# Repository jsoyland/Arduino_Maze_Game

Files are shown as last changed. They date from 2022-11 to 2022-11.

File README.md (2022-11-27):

# Arduino Maze Game

We thought that it might be fun to make a "video game console" out of an Arduino and decided on a maze game.  

### Console
The design for the console was hand-drawn and then reproduced in OpenSCAD.

### Wiring 

We used a ILI9341 320x240 screen and an Arudino Nano.  Initially it only showed a white screen, but it tuns out that all its inputs require to be 3.3V, which meant we needed a 3.3V-5V logic level converter in between the Arduino and the screen.  With that in place, the wiring looks like:
|Display | Arduino |
| ----- | ----- |
| VCC | 3v3 |
| GND | GND | 
| CS | 10 | 
| RESET | 3v3 | 
| DC | 9 | 
| SDI(MOSI) | 11 | 
| SCK | 13|  
| LED | 3v3 | 
| SDO(MISO) | 12 | 
| T_CLK | 13 |
| T_CS | 8 |
| T_DIN | 11 |
| T_DO | 12 |
| T_IRQ | not connected |

We aren't using any of the touch capabilities here, though I went ahead and wired it up.  I don't totally understand it but Arduno has an ["SPI" interface](https://www.arduino.cc/reference/en/language/functions/communication/spi/) that the touchscreen and display devices both use.  The Output/Input/Clock pins are shared between the two peripherals, which the Chip Select is different (here it's pins 10 and 8).

Also wired up a joystick to control the maze:
| Thumbstick | Arduino |
| SW | 2 |
| VRY | A0 |
| VRX | A1 |
| +5V | 5V |
| GND | GND |

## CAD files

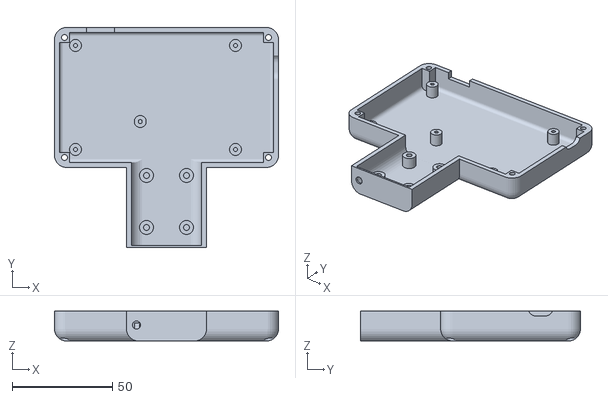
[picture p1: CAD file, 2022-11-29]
console.stl
112.0 x 110.0 x 15.0

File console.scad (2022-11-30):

// Higher definition curves
$fs = 0.01;


difference(){//temporary - cut off back half

union(){
    difference(){ 
        // Body
        union(){
            // Screen Box
            roundedcube([112, 70, 30], true, 6);
            // Handle
            translate([0, -70, 0]) roundedcube([40, 130, 30], true, 6);
        }

        //Screen Hole (67mm x 50 mm)
        translate([0, 0, 10]) cube([67.01, 50.01, 30], true);
        
        // Thumbstick hole
        translate([0, -52, 10]) cylinder(30, 11, 11, true);
        
        union(){ // Interior
            //screen
            //translate([0, 0, 0]) roundedcube([105, 65, 25], true, 6);
            translate([0, 0, 0]) roundedcube([107, 65, 25], true, 2);
            //handle
            translate([0, -70, 0]) roundedcube([35,125,25], true, 6);
        }
            
        // subtract rounded corners on display hole
        translate([0 , 0, .01]) 
            difference(){
                difference(){
                    translate([0, 0, 14.5]) cube([69, 52, 1], true);
                    translate([0, 0, 14.5]) cube([67, 50, 1.1], true);
                }
                
                union(){
                    translate([0, 26, 14]) rotate([90, 0, 90]) cylinder(70, 1, 1, true);
                    translate([0, -26, 14]) rotate([90, 0, 90]) cylinder(70, 1, 1, true);
                    translate([34.5, 0, 14]) rotate([90, 0, 0]) cylinder(52, 1, 1, true);
                    translate([-34.5, 0, 14]) rotate([90, 0, 0]) cylinder(52, 1, 1, true);
                }
        }

        // screw holes for screen
        translate([(110/2)-15, 0, 12.5-(3.43/2)]) {
                translate([0, 49/2, 0]) cylinder(7, 1.5, 1.5, true);
                translate([0, -49/2, 0]) cylinder(7, 1.5, 1.5, true);
        }

        translate([-((110/2)-10), 0, 12.5-(3.43/2)]) {
                translate([0, 49/2, 0]) cylinder(7, 1.5, 1.5, true);
                translate([0, -49/2, 0]) cylinder(7, 1.5, 1.5, true);
        }
        
       
        // screw holes for body
        
        translate([-30/2, -130, 0]) {
            cylinder(27.01, 1.5, 1.5, true);
            translate([0, 0, -14.5]) cylinder(2, 2.75, 2.75, true);
        }
        translate([30/2, -130, 0]) {
            cylinder(27.01, 1.5, 1.5, true);
            translate([0, 0, -14.5]) cylinder(2, 2.75, 2.75, true);
        }
        translate([102/2, 60/2, 0]) {
            cylinder(27.01, 1.5, 1.5, true);
            translate([0, 0, -14.5]) cylinder(2, 2.75, 2.75, true);
        }
        
        translate([102/2, -60/2, 0]) {
            cylinder(27.01, 1.5, 1.5, true);
            translate([0, 0, -14.5]) cylinder(2, 2.75, 2.75, true);
        }
        
        translate([-102/2, 60/2, 0]) {
            cylinder(27.01, 1.5, 1.5, true);
            translate([0, 0, -14.5]) cylinder(2, 2.75, 2.75, true);
        }
        
        translate([-102/2, -60/2, 0]) {
            cylinder(27.01, 1.5, 1.5, true);
            translate([0, 0, -14.5]) cylinder(2, 2.75, 2.75, true);
        }
        
        // Hole for switch
        translate([-33, 35, 1]){
            cube([14, 10, 9.5], true);
        }
        
        // Hole for USB-C port
        translate([55, 13, 1.5]){ 
            union(){
               //#translate([0, 2.25, 0]) rotate([0, 90, 0]) cylinder(10, 3.5, 3.5, true);  
               //#translate([0, -2.25, 0]) rotate([0, 90, 0]) cylinder(10, 3.5, 3.5, true);  
               translate([0, 2.25, 0]) rotate([0, 90, 0]) cylinder(10, 4, 4, true);  
               translate([0, -2.25, 0]) rotate([0, 90, 0]) cylinder(10, 4, 4, true);               
               cube([10, 4.5, 8], true );           
            }
        }
        
    }
    
    // close off battery compartment, but leave a 2x3mm hole for connector
     translate([0, -75, 0]) difference(){
       cube([35, 2, 25], true);
       translate([15, 0, -7]) rotate([90, 0, 0]) cylinder(4, 2, 2, true);
     }
            
    // Mounting blocks for screen.  
    // Height above base: 3.43 mm
    // Screw hole 3mm  
    translate([(110/2)-15, 0, 12.5-(4.44/2)]) 
        difference(){
            cube([5.00, 55, 4.43], true);
            translate([0, 50/2, 0]) cylinder(6, 1.5, 1.5, true);
            translate([0, -50/2, 0]) cylinder(6, 1.5, 1.5, true);
            cube([5.01, 44, 4.44], true);
        }
        
    translate([-((110/2)-10.01), 0, 12.5-(4.44/2)]) 
        // Bizzarely adding .01mm to x here addresses an 
        // "Object may not be a valid 2-manifold and may need repair!" error
        difference(){
            cube([5.00, 55, 4.43], true);
            translate([0, 50/2, 0]) cylinder(6, 1.5, 1.5, true);
            translate([0, -50/2, 0]) cylinder(6, 1.5, 1.5, true);
            cube([5.01, 44, 4.44], true);
        }
        
      // Standoffs for circuit board.  Trying cylinders
      circuit_board_standoff_height=6.5;
      translate([-(17/2)+4, 0, (-(25/2)+(circuit_board_standoff_height/2))]) 
        difference(){
            union(){
                translate([-82/2, 53/2, 0]) cylinder(circuit_board_standoff_height, 3, 3, true);
                translate([-82/2, -53/2, 0]) cylinder(circuit_board_standoff_height, 3, 3, true);
                translate([-82/2 + 33.38, -52/2 + 13.97, 0]) cylinder(circuit_board_standoff_height, 3, 3, true);
                translate([82/2, 53/2, 0]) cylinder(circuit_board_standoff_height, 3, 3, true);
                translate([82/2, -53/2, 0]) cylinder(circuit_board_standoff_height, 3, 3, true);
            }
            translate([-82/2, 53/2, 0]) cylinder(circuit_board_standoff_height+0.1, 1, 1, true);
            translate([-82/2, -53/2, 0]) cylinder(circuit_board_standoff_height+0.1, 1, 1, true);
            translate([-82/2 + 33.38, -52/2 + 13.97, 0]) cylinder(circuit_board_standoff_height+.1, 1, 1, true);
            translate([82/2, 53/2, 0]) cylinder(circuit_board_standoff_height+0.1, 1, 1, true);
            translate([82/2, -53/2, 0]) cylinder(circuit_board_standoff_height+0.1, 1, 1, true);
        }        

/*
    translate([-((110/2)-10), 0, 12.5-(4.94/2)]) 
        difference(){
            cube([5.00, 54, 4.93], true);
            translate([0, 49/2, 0]) cylinder(6, 1.5, 1.5, true);
            translate([0, -49/2, 0]) cylinder(6, 1.5, 1.5, true);
            cube([5.01, 43, 4.94], true);
        }
*/            
            
    // Mounting block for thumbstick
    thumbstick_standoff_height=6;
    translate([0, -50, -(25-thumbstick_standoff_height)/2]) {
        difference(){
            union(){
                translate([20/2, (26/2)-2, 0]) cylinder(thumbstick_standoff_height, 3.5, 3.5, true);
                translate([-20/2, (26/2)-2, 0]) cylinder(thumbstick_standoff_height, 3.5, 3.5, true);
                translate([-20/2, -(26/2)-2, 0]) cylinder(thumbstick_standoff_height, 3.5, 3.5, true);
                translate([20/2, -(26/2)-2, 0]) cylinder(thumbstick_standoff_height, 3.5, 3.5, true);
            }
            //cube([27, 36, 7], true);    
            translate([20/2, (26/2)-2, 0]) cylinder(thumbstick_standoff_height+.1, 1.5, 1.5, true);
            translate([-20/2, (26/2)-2, 0]) cylinder(thumbstick_standoff_height+.1, 1.5, 1.5, true);
            translate([-20/2, -(26/2)-2, 0]) cylinder(thumbstick_standoff_height+.1, 1.5, 1.5, true);
            translate([20/2, -(26/2)-2, 0]) cylinder(thumbstick_standoff_height+.1, 1.5, 1.5, true);
            //translate([0, -2, 0]) cube([27.01, 18.01, 7.01], true);
            //translate([0, 0, 0]) cube([12.01, 36.01, 7.01], true);
        }
    }
    
    // Body Screws - Whatever it's called, the bits that hold the halves together.
    
    //lower-left handle
    translate([-30/2, -130, 0]) difference(){
        cube([5, 5, 24.5], true);
        cylinder(26.1, 1.5, 1.5, true);
    }
    
    //lower-right handle
    translate([30/2, -130, 0]) difference(){
        cube([5, 5, 25], true);
        cylinder(26.1, 1.5, 1.5, true);
    }
  
    //upper-right display
    translate([102/2, 60/2, 0]) difference(){
        cube([5, 5, 24.5], true);
        cylinder(26.1, 1.5, 1.5, true);
    }
    
    //lower-right display
    translate([102/2, -60/2, 0]) difference(){
        cube([5, 5, 25], true);
        cylinder(26.1, 1.5, 1.5, true);
    }
    
    //upper-left display
    translate([-102/2, 60/2, 0]) difference(){
        //cube([5, 5, 25], true);
        cylinder(25, 2.5, 2.5, true);
        cylinder(26.1, 1.5, 1.5, true);
    }
    
    //lower-left display
    translate([-102/2, -60/2, 0]) difference(){
        //cube([5, 5, 25], true);
        cylinder(25, 2.5, 2.5, true);
        cylinder(26.1, 1.5, 1.5, true);
    }
    
}
    
    
// temporary - cut off back half
//translate([0, 0, -15]) cube([400, 400, 30], true);
// temporary - cut off front half
 translate([0, 0, 15]) cube([400, 400, 30], true);

// Temporary - cut off most of back
//translate([0, 0, -8]) cube([400, 400, 30], true);
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

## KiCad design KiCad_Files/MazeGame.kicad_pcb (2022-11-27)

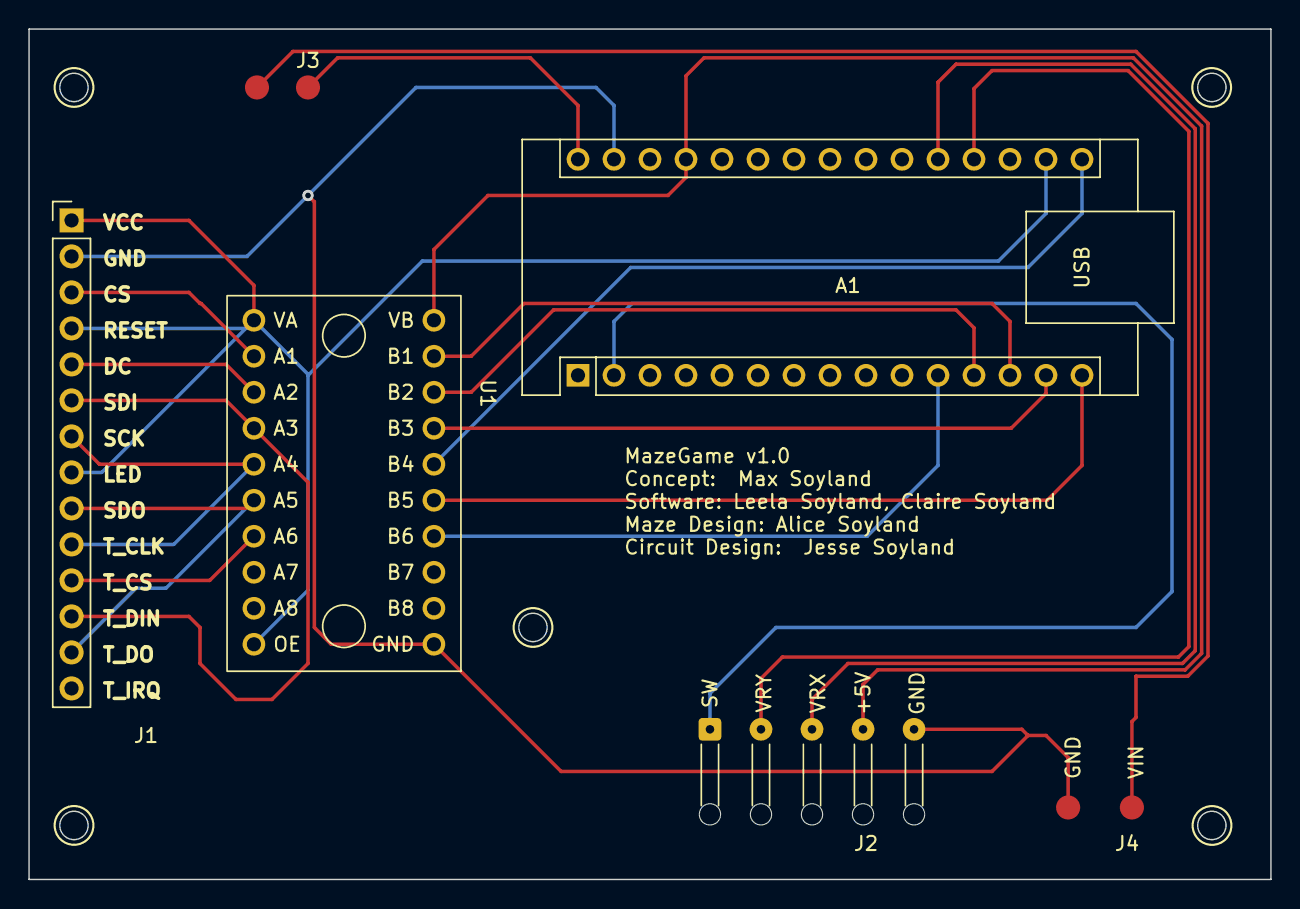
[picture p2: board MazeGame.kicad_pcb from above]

Board: 2 copper layers, 87.6 x 60.0 mm, 6 parts (0 on the bottom side), 20 nets.

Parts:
A1: Arduino_Nano_v3.x; Arduino_Nano
J1: ILI9341; PinHeader_1x14_P2.54mm_Vertical
J2: Thumbstick; SolderWire-0.1sqmm_1x05_P3.6mm_D0.4mm_OD1mm_Relief
J3: Switch; SolderWire-0.1sqmm_1x02_P3.6mm_D0.4mm_OD1mm
J4: Power; SolderWire-0.25sqmm_1x02_P4.5mm_D0.65mm_OD2mm
U1: EPLZON_TXS0108E; EPLZON TXS0108E Board

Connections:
unnamed: A1.11 (D8), U1.7 (B6)
unnamed: A1.14 (D11), U1.4 (B3)
unnamed: A1.15 (D12), U1.6 (B5)
unnamed: A1.16 (D13), U1.5 (B4)
unnamed: A1.17 (3V3), J1.1 (VCC), J1.4 (RESET), J1.8 (LED), U1.11 (VA), U1.20 (OE)
unnamed: J1.3 (CS), U1.12 (A1)
unnamed: J1.5 (DC), U1.13 (A2)
unnamed: J1.6 (SDI), J1.12 (T_DIN), U1.14 (A3)
unnamed: J1.7 (SCK), J1.10 (T_CLK), U1.15 (A4)
unnamed: A1.2 (D0/RX), J2.1
unnamed: A1.19 (A0), J2.2
unnamed: A1.20 (A1), J2.3
unnamed: A1.27 (+5V), J2.4, U1.1 (VB)
unnamed: A1.29 (GND), J1.2 (GND), J2.5, J4.2, U1.10 (GND)
unnamed: A1.30 (VIN), J3.1
unnamed: J3.2, J4.1
unnamed: A1.13 (D10), U1.2 (B1)
unnamed: A1.12 (D9), U1.3 (B2)
unnamed: J1.9 (SDO), J1.13 (T_DO), U1.16 (A5)
unnamed: J1.11 (T_CS), U1.17 (A6)

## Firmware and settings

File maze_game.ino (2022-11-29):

#include "SPI.h"
#include "Adafruit_GFX.h"
#include "Adafruit_ILI9341.h"

#define TFT_DC 9
#define TFT_CS 10
Adafruit_ILI9341 tft = Adafruit_ILI9341(TFT_CS, TFT_DC);
#define  CLK_PIN   13
#define DATA_PIN  11
#define CS_PIN    10

#define VERT_PIN A1
#define HORZ_PIN A0
#define SEL_PIN  0 // Was originally D2 but I made a mistake on the PCB.  In a stroke of luck D0 works.

int x = 0;
int y = 0;

int x_pos = 0;
int y_pos = 0;

//display is 320x240 so a pixelsize of 8 means we can do 40 x 30 

#define MAZEWIDTH  320//40*8
#define MAZEHEIGHT 240//30*8
#define PIXELSIZE  1


void setup() {
  tft.begin();

  pinMode(VERT_PIN, INPUT);
  pinMode(HORZ_PIN, INPUT);
  pinMode(SEL_PIN, INPUT_PULLUP);
  tft.setRotation(3);             // https://learn.adafruit.com/adafruit-gfx-graphics-library/rotating-the-display
  tft.fillScreen(ILI9341_BLACK);
//  drawMaze();
}

//https://www.youtube.com/watch?v=eBuFZ2glyvc

void loop() {
  int horz = analogRead(HORZ_PIN);
  int vert = analogRead(VERT_PIN);

/*
  tft.setCursor(10, 100);
  tft.setTextColor(ILI9341_RED, ILI9341_YELLOW);
  tft.setTextSize(3);
  tft.println("X: " + String(x_pos) + "    "  + "\n horz: " + String(horz) + "    ");
  tft.setCursor(10, 200);
  tft.setTextColor(ILI9341_BLUE, ILI9341_YELLOW);
  tft.println("Y: " + String(y_pos) + "    " + "\n vert: " + String(vert) + "    ");
*/

if ((horz > 550) && (x_pos >= 0)) {
  x_pos=x_pos - PIXELSIZE;
}
if ((horz < 450) && (x_pos <= MAZEWIDTH)) {
  x_pos = x_pos + PIXELSIZE;
}
if ((vert > 550) && (y_pos <= MAZEHEIGHT)){
  y_pos=y_pos + PIXELSIZE;
}
if ((vert < 450) && (y_pos >= 0)){
  y_pos = y_pos - PIXELSIZE;
}


tft.fillRect((x_pos), (y_pos), PIXELSIZE, PIXELSIZE, ILI9341_GREEN);

  if (digitalRead(SEL_PIN) == LOW) {
    tft.fillScreen(ILI9341_BLACK);
  }
  delay(10);
}







bool Maze[] = {
  1,0,1,0,1,0,1,0,1,0,1,0,1,0,1,0,1,0,1,0,1,0,1,0,1,0,1,0,1,0,1,0,1,0,1,0,1,0,1,0, 
  0,1,1,1,1,1,1,1,1,1,1,1,1,1,1,1,1,1,1,1,1,1,1,1,1,1,1,1,1,1,1,1,1,1,1,1,1,1,1,1,
  1,1,1,1,1,1,1,1,1,1,1,1,1,1,1,1,1,1,1,1,1,1,1,1,1,1,1,1,1,1,1,1,1,1,1,1,1,1,1,0,
  0,1,1,1,1,1,1,1,1,1,1,1,1,1,1,1,1,1,1,1,1,1,1,1,1,1,1,1,1,1,1,1,1,1,1,1,1,1,1,1,
  1,1,1,1,1,1,1,1,1,1,1,1,1,1,1,1,1,1,1,1,1,1,1,1,1,1,1,1,1,1,1,1,1,1,1,1,1,1,1,0,
  0,1,1,1,1,1,1,1,1,1,1,1,1,1,1,1,1,1,1,1,1,1,1,1,1,1,1,1,1,1,1,1,1,1,1,1,1,1,1,1,
  1,1,1,1,1,1,1,1,1,1,1,1,1,1,1,1,1,1,1,1,1,1,1,1,1,1,1,1,1,1,1,1,1,1,1,1,1,1,1,0,
  0,1,1,1,1,1,1,1,1,1,1,1,1,1,1,1,1,1,1,1,1,1,1,1,1,1,1,1,1,1,1,1,1,1,1,1,1,1,1,1,
  1,1,1,1,1,1,1,1,1,1,1,1,1,1,1,1,1,1,1,1,1,1,1,1,1,1,1,1,1,1,1,1,1,1,1,1,1,1,1,0,
  0,1,1,1,1,1,1,1,1,1,1,1,1,1,1,1,1,1,1,1,1,1,1,1,1,1,1,1,1,1,1,1,1,1,1,1,1,1,1,1,
  1,1,1,1,1,1,1,1,1,1,1,1,1,1,1,1,1,1,1,1,1,1,1,1,1,1,1,1,1,1,1,1,1,1,1,1,1,1,1,0,
  0,1,1,1,1,1,1,1,1,1,1,1,1,1,1,1,1,1,1,1,1,1,1,1,1,1,1,1,1,1,1,1,1,1,1,1,1,1,1,1,
  1,1,1,1,1,1,1,1,1,1,1,1,1,1,1,1,1,1,1,1,1,1,1,1,1,1,1,1,1,1,1,1,1,1,1,1,1,1,1,0,
  0,1,1,1,1,1,1,1,1,1,1,1,1,1,1,1,1,1,1,1,1,1,1,1,1,1,1,1,1,1,1,1,1,1,1,1,1,1,1,1,
  1,1,1,1,1,1,1,1,1,1,1,1,1,1,1,1,1,1,1,1,1,1,1,1,1,1,1,1,1,1,1,1,1,1,1,1,1,1,1,0,
  0,1,1,1,1,1,1,1,1,1,1,1,1,1,1,1,1,1,1,1,1,1,1,1,1,1,1,1,1,1,1,1,1,1,1,1,1,1,1,1,
  1,1,1,1,1,1,1,1,1,1,1,1,1,1,1,1,1,1,1,1,1,1,1,1,1,1,1,1,1,1,1,1,1,1,1,1,1,1,1,0,
  0,1,1,1,1,1,1,1,1,1,1,1,1,1,1,1,1,1,1,1,1,1,1,1,1,1,1,1,1,1,1,1,1,1,1,1,1,1,1,1,
  1,1,1,1,1,1,1,1,1,1,1,1,1,1,1,1,1,1,1,1,1,1,1,1,1,1,1,1,1,1,1,1,1,1,1,1,1,1,1,0,
  0,1,1,1,1,1,1,1,1,1,1,1,1,1,1,1,1,1,1,1,1,1,1,1,1,1,1,1,1,1,1,1,1,1,1,1,1,1,1,1,
  1,1,1,1,1,1,1,1,1,1,1,1,1,1,1,1,1,1,1,1,1,1,1,1,1,1,1,1,1,1,1,1,1,1,1,1,1,1,1,0,
  0,1,1,1,1,1,1,1,1,1,1,1,1,1,1,1,1,1,1,1,1,1,1,1,1,1,1,1,1,1,1,1,1,1,1,1,1,1,1,1,
  1,1,1,1,1,1,1,1,1,1,1,1,1,1,1,1,1,1,1,1,1,1,1,1,1,1,1,1,1,1,1,1,1,1,1,1,1,1,1,0,
  0,1,1,1,1,1,1,1,1,1,1,1,1,1,1,1,1,1,1,1,1,1,1,1,1,1,1,1,1,1,1,1,1,1,1,1,1,1,1,1,
  1,1,1,1,1,1,1,1,1,1,1,1,1,1,1,1,1,1,1,1,1,1,1,1,1,1,1,1,1,1,1,1,1,1,1,1,1,1,1,0,
  0,1,1,1,1,1,1,1,1,1,1,1,1,1,1,1,1,1,1,1,1,1,1,1,1,1,1,1,1,1,1,1,1,1,1,1,1,1,1,1,
  1,1,1,1,1,1,1,1,1,1,1,1,1,1,1,1,1,1,1,1,1,1,1,1,1,1,1,1,1,1,1,1,1,1,1,1,1,1,1,0,
  0,1,1,1,1,1,1,1,1,1,1,1,1,1,1,1,1,1,1,1,1,1,1,1,1,1,1,1,1,1,1,1,1,1,1,1,1,1,1,1,
  1,1,1,1,1,1,1,1,1,1,1,1,1,1,1,1,1,1,1,1,1,1,1,1,1,1,1,1,1,1,1,1,1,1,1,1,1,1,1,0,
  0,1,0,1,0,1,0,1,0,1,0,1,0,1,0,1,0,1,0,1,0,1,0,1,0,1,0,1,0,1,0,1,0,1,0,1,0,1,0,1
};


void drawMaze(){
  uint16_t x, y;
  bool wall;
  
  for(x=0;x<MAZEWIDTH;x++){
    for(y=0;y<MAZEHEIGHT;y++){
      wall=readPixel(x,y);
      if (wall){
        tft.fillRect((x*PIXELSIZE), (y*PIXELSIZE), PIXELSIZE, PIXELSIZE, ILI9341_YELLOW);
      }
    }
  }

}

bool readPixel(uint16_t x, uint16_t y){
  return Maze[(y*MAZEWIDTH)+x];
}

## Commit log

2022-10-12 Widen thumbstick hole a bit
    [console.scad]
2022-10-12 Widen top for mounting screen
    [console.scad]
2022-10-13 Slice in half, add interior space
    [console.scad]
2022-10-13 Rounded corners on display hole
    [console.scad]
2022-10-15 Add screw holes for screen
    [console.scad]
2022-10-15 Add barrier for battery
    [console.scad]
2022-10-15 Add hole for battery cord
    [console.scad]
2022-10-15 Shorten handle by 5mm
    [console.scad]
2022-10-16 Screen standoffs reduce to 3.43mm
    [console.scad]
2022-10-16 Mounting block for thumbstick
    [console.scad]
2022-10-16 Grouping adds/subtracts, fix indents
    [console.scad]
2022-10-16 Screw holes for body halves
    [console.scad]
2022-10-16 Reduce size of thumbstick mounts
    [console.scad]
2022-10-17 Minor cosmetic adjustments
    [console.scad]
2022-10-17 Weird fix for 'valid 2-manifold' error
    [console.scad]
2022-10-17 Reduce roundness of interior volume
    [console.scad]
2022-10-17 screen mounting blocks 1mm further apart
    [console.scad]
2022-10-17 screen mounting blocks .5mm shorter
    [console.scad]
2022-10-18 screen mounting blocks - adjustment
    [console.scad]
2022-10-19 Mounting post for circuit board. Cylinders
    [console.scad]
2022-10-19 Parameterize circuit board standoff
    [console.scad]
2022-10-19 move thumbstick hole 2mm down
    [console.scad]
2022-10-19 ignore .DS_Store 🤦🏻‍
2022-10-19 Add 1mm to spacing of circuit standoffs
    [console.scad]
2022-10-19 Convert thumbstick blocks to cylinders
    [console.scad]
2022-10-20 Add hole for switch
    [console.scad]
2022-10-20 Adjust position of battery wire hole
    [console.scad]
2022-10-20 Rotating arduino board 90°
    [console.scad]
2022-10-24 Add USB_C Hole
    [console.scad]
2022-10-24 Single larger board vs two
    [console.scad]
2022-10-24 Make mount posts a little thicker
    [console.scad]
2022-10-26 Dimensional adjustments after test print
    [console.scad]
2022-10-26 USB-C Port Adjustment
    [console.scad]
2022-11-27 Update with touchscreen and joystick wirings
2022-11-27 Minor updates
    [console.scad]
2022-11-27 Add KiCad circuit diagram and layout
    [MazeGame.kicad_pcb, MazeGame.kicad_sch]
2022-11-28 Adjust circuit standoffs for new PCB
    [console.scad]
2022-11-28 Move USB-C port to align better with new PCB
    [console.scad]
2022-11-29 Thumbstick mods for PCB.
    [console.stl]
2022-11-29 Adjust circuit standoffs
    [console.scad]
2022-11-29 Change pin for thumbstick button
    I originally had D2 in the code and tested with that. When making
    the circuit board accidentally used "pin 2" which was RX0.
    In a stroke of luck it turns out that RX0 can be initialized as
    a digital input (D0), so changed to use that instead.
2022-11-30 Trying cylinders for body mounts
    [console.scad]
2022-11-30 Move USB-C hole down 2mm
    [console.scad]
2022-11-30 Adjust circuit board mount holes
    [console.scad]
